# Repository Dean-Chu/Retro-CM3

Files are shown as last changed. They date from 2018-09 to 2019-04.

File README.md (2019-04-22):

# Retro-CM3

Yet another retropie console. 

Build with Raspberry Pi Compute Module 3 Lite. As powerful as Rpi3B, but as small as Rpi 0.

The final size of this console is within 155x61x15mm with 2 hours batter life.

Support most of the emulators provided by retropie.

Run PS1 N64 smoothly, able to run most 2D and some of 3D PSP games.

Assamble video: https://www.bilibili.com/video/av24430157

Flashable image： http://soft.nyko.moe/Game/RetroPie/CM3/retro-cm3v42-no-rom-v3.7z
Alternative link: https://drive.google.com/file/d/1JxBlyW3KhkUhTjVssIsfI8lL1l42jLt7/view?usp=sharing

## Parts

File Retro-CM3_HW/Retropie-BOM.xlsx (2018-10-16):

COMPONENT |  | footprint | value
SKRRAAE010 | A, B, DOWN, LEFT, RIGHT, UP, X, Y | SKRRAAE010
AN9250 | A1 | AN9520
XH2.54-2p | BT1 | XH2.54-2
CAP | C1, C4 | 0603-CAP | 2.2nF
CAP | C12, C28, C42, C43, C44, C51, C55, C58, C60 | 0805-CAP | 10uF
CAP | C19 | 0603-CAP | 0.33uF
CAP | C2, C45, C46, C48 | 1206-CAP | 47uF
CAP | C21, C32, C33, C37, C38, C39 | C3216 | 100uF/6v
CAP | C25, C31, C34, C36 | 0603-CAP | 0.1uF
CAP | C3, C7, C8, C9, C10, C13, C14, C17, C18, C24, C29, C30, C35, C49, C52, C53, C56, C59, C61, C62 | 0603-CAP | 100nF
CAP | C5, C15, C16, C20, C22, C26, C27,C40, C41 | 0805-CAP | 22uF
CAP | C50 | 0805-CAP | 3.3uF
CAP | C54, C57 | 0603-CAP | 2.2uF
PJS008-2000-0 | CN1 | PJS008-2000-0
LED-GREEN | D1 | 0603_LED
LED-RED | D2 | 0603_LED
LED-BLUE | D3 | 0603_LED
BAT54C | D4 | SOT-23_L
1N5819/SS14 | D6 | SMA
PJ-327 | J1 | pj-327 |  | 手补
Micro USB | J2 | USB micro
BUTTONS | L, R | 6*6*5mm |  | 手补
CD32 INDUCTOR | L1 | CD32 | 22uH
MHCI04020-1R2M | L2 | MHCI04020-1R2M | 1.2uH
MHCI04020-4R7M | L3, L4 | MHCI04020-4R7M | 4.7uH
SPEAKER | LS1 | 28*9*4 |  | 手补
SKRTLABE010 | PWR | SKRTLABE010
8050 | Q1, Q4, Q5, Q7 | SOT-23_L
Si2305 | Q2, Q3, Q6 | SOT23-3L
RES | R1,R20 | 0603-RES | 0
RES | R10, R11, R24, R39, R45 | 0603-RES | 100K
RES | R12, R16, R18, R22, R23, R34, R37, R41 | 0603-RES | 100K
RES | R14, R17 | 0603-RES | 4.7
RES | R2, R13, R15, R28, R30, R38, R44, R9 | 0603-RES | 1K
RES | R21 | 0603-RES | 200K
RES | R25 | 0603-RES | 0
RES | R26, R32 | 0603-RES | 20K
RES | R3, R4 | 0603-RES | 470
RES | R33 | 0603-RES | 820
RES | R35 | 0603-RES | 200K
RES | R36 | 0603-RES | 22K
RES | R5, R6, R7, R8, R19, R27, R29, R40 | 0603-RES | 10K
SKRAAME010 | SEL, STA | SKRAAME010
STM8S003F3 | U1 | TSOP65P640-20AN
PCM5100APWR | U10 | TSOP-20
AMP 2-1827236-4 | U11 | DDR2-SODIMM
RL-UM02BS | U2 | RL-UM02BS
TDA2822 | U3 | SOP-8
SY8008B | U4, U6 | SOT23-5AL
SP6205-3.3 | U5, U7 | SOT23-5AL
MP2617-GL | U8 | QFN-20
PT4103 | U9 | SOT26A-6N
FH35C-49S-0.3SHW | U12

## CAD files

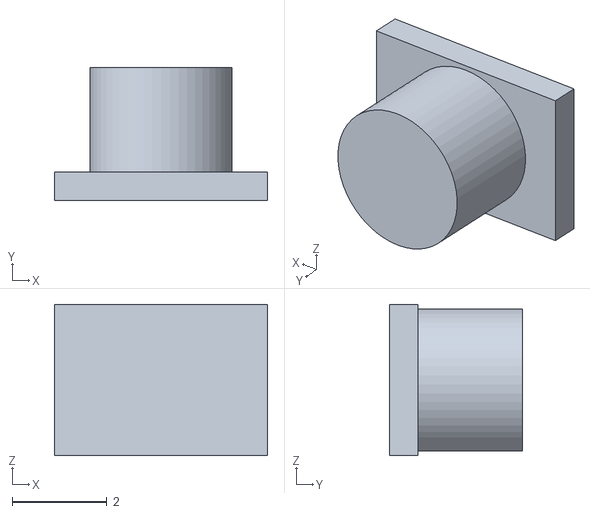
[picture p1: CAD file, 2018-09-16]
Retro-CM3_STL/PWR.STL
4.50 x 2.80 x 3.20

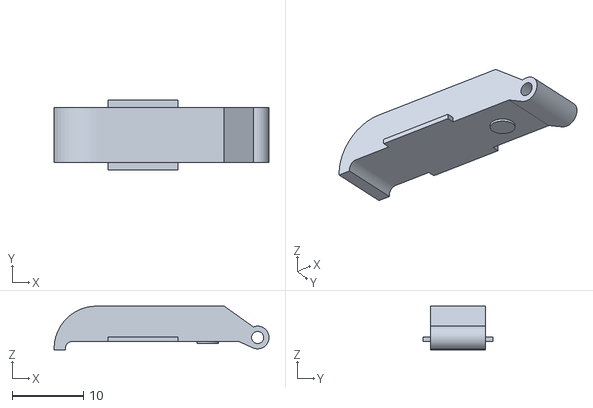
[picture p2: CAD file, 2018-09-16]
Retro-CM3_STL/LR.STL
30.2 x 9.80 x 6.17

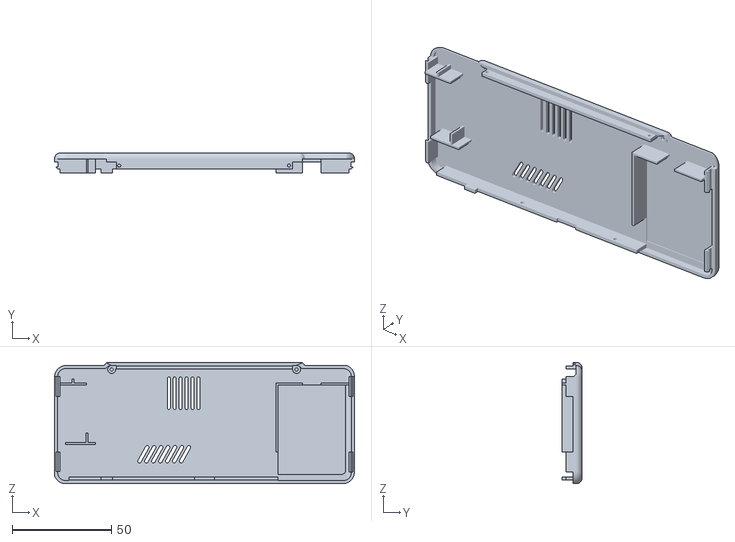
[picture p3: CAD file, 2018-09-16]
Retro-CM3_STL/BOTTOM-v4.STL
151.2 x 10.2 x 61.2

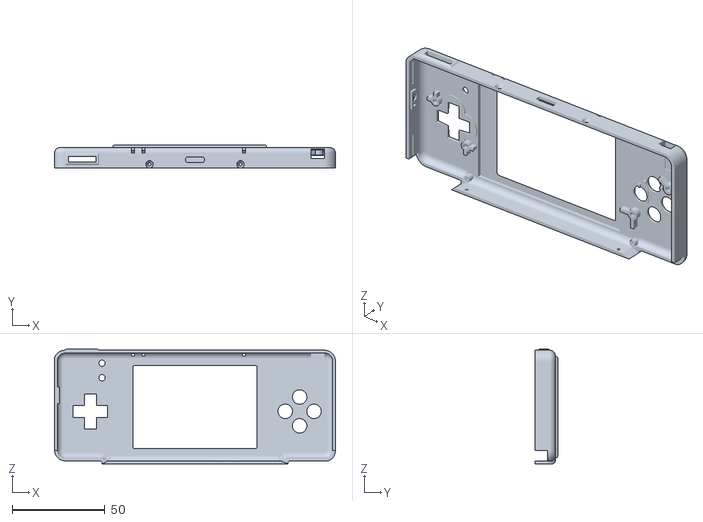
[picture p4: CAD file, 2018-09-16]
Retro-CM3_STL/TOP-v4.STL
151.2 x 12.4 x 61.8

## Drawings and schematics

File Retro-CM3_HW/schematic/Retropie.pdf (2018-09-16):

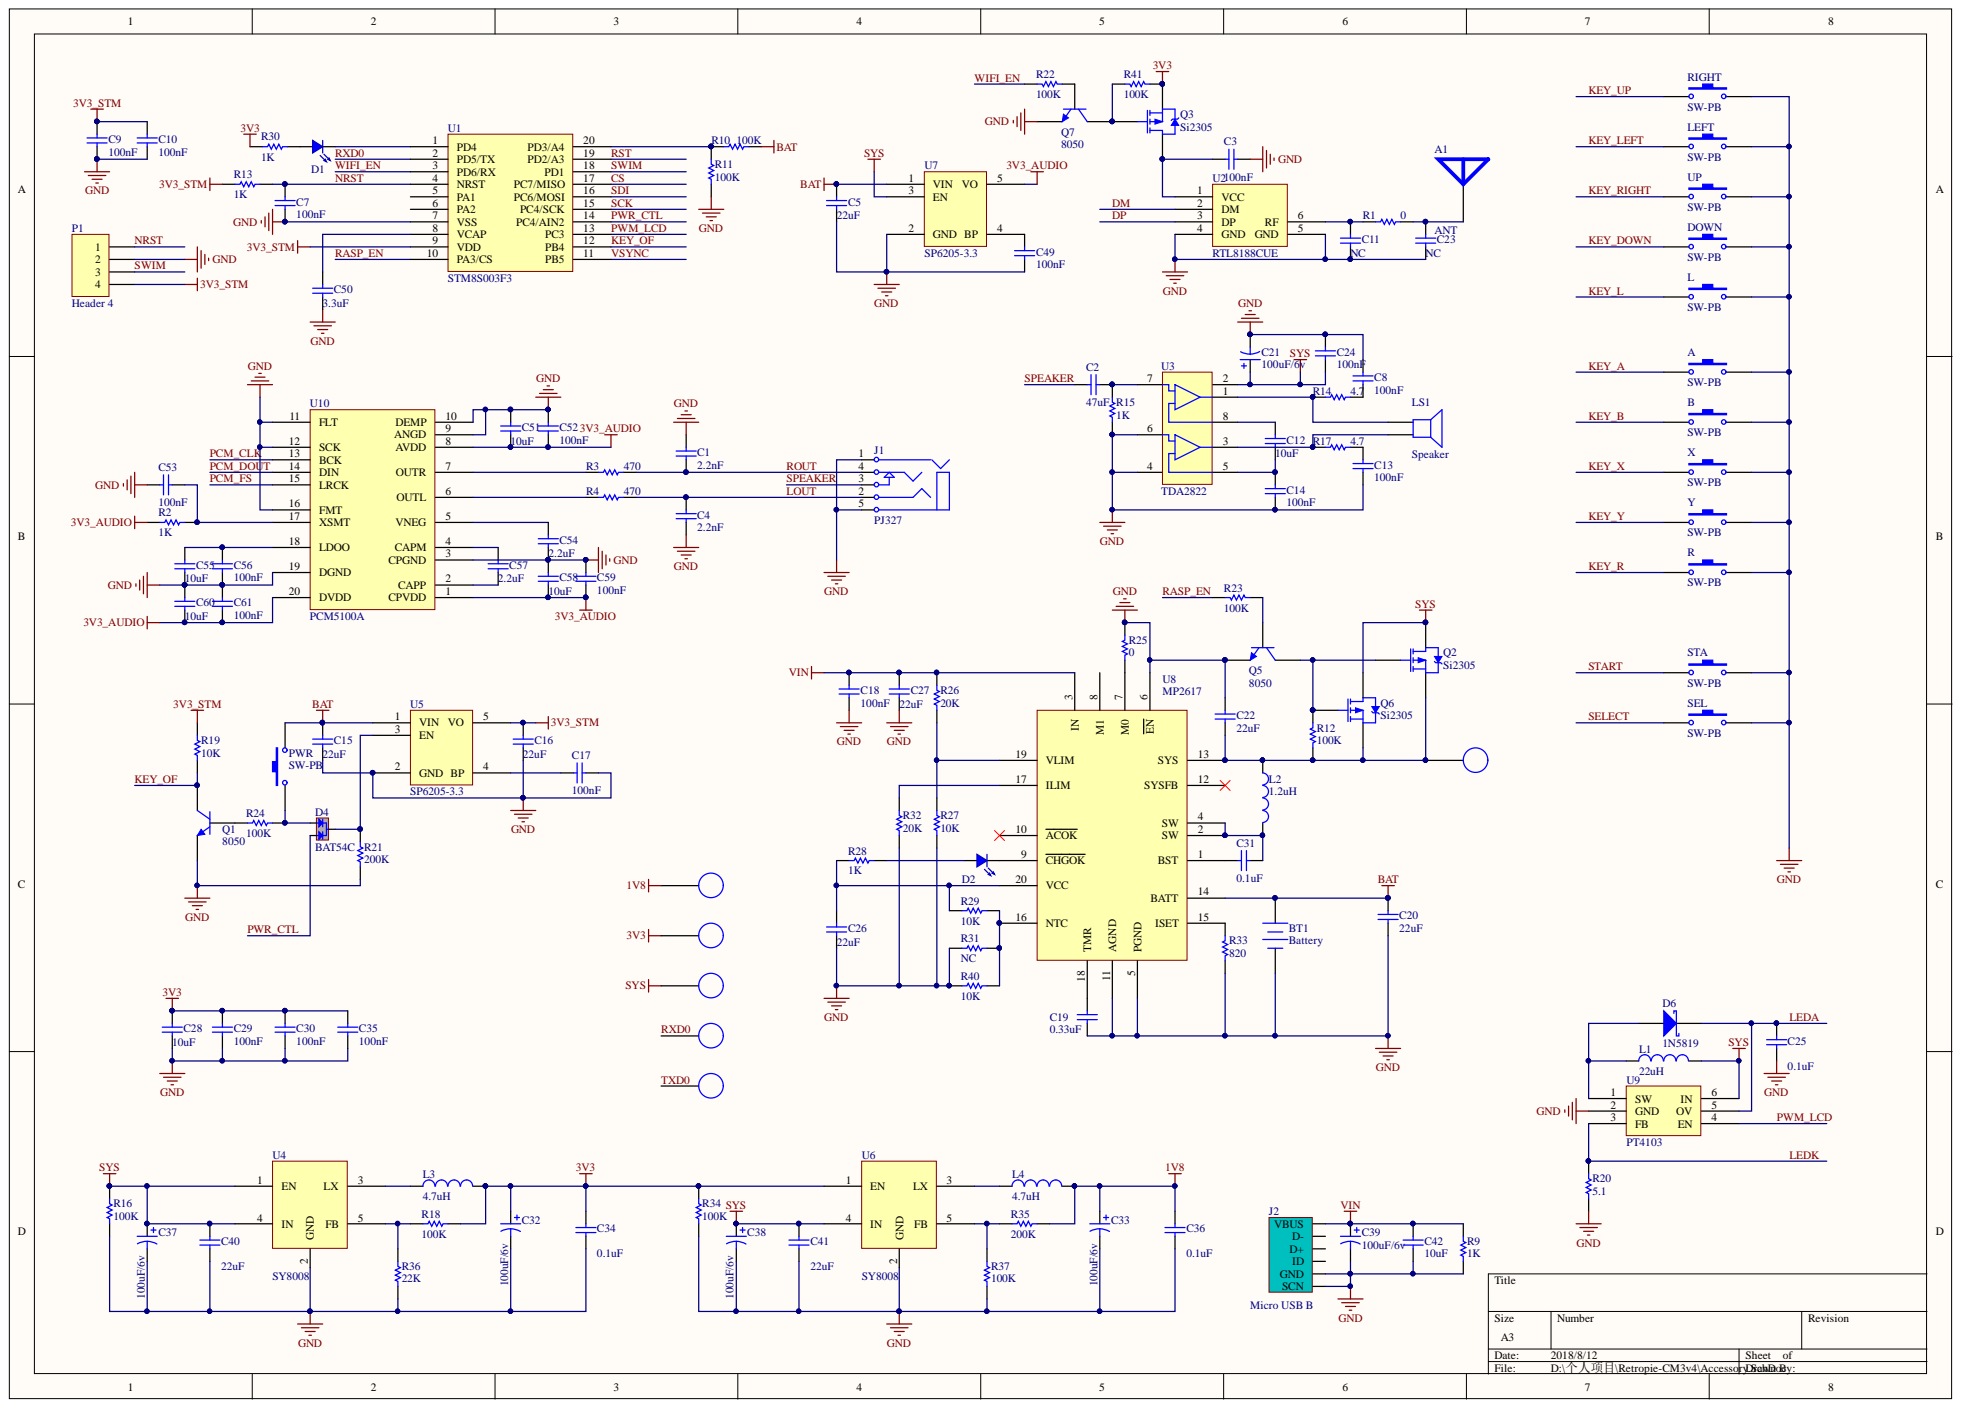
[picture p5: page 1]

BCK 13

LDOO 18

10uF | 100nF | | DVDD 20

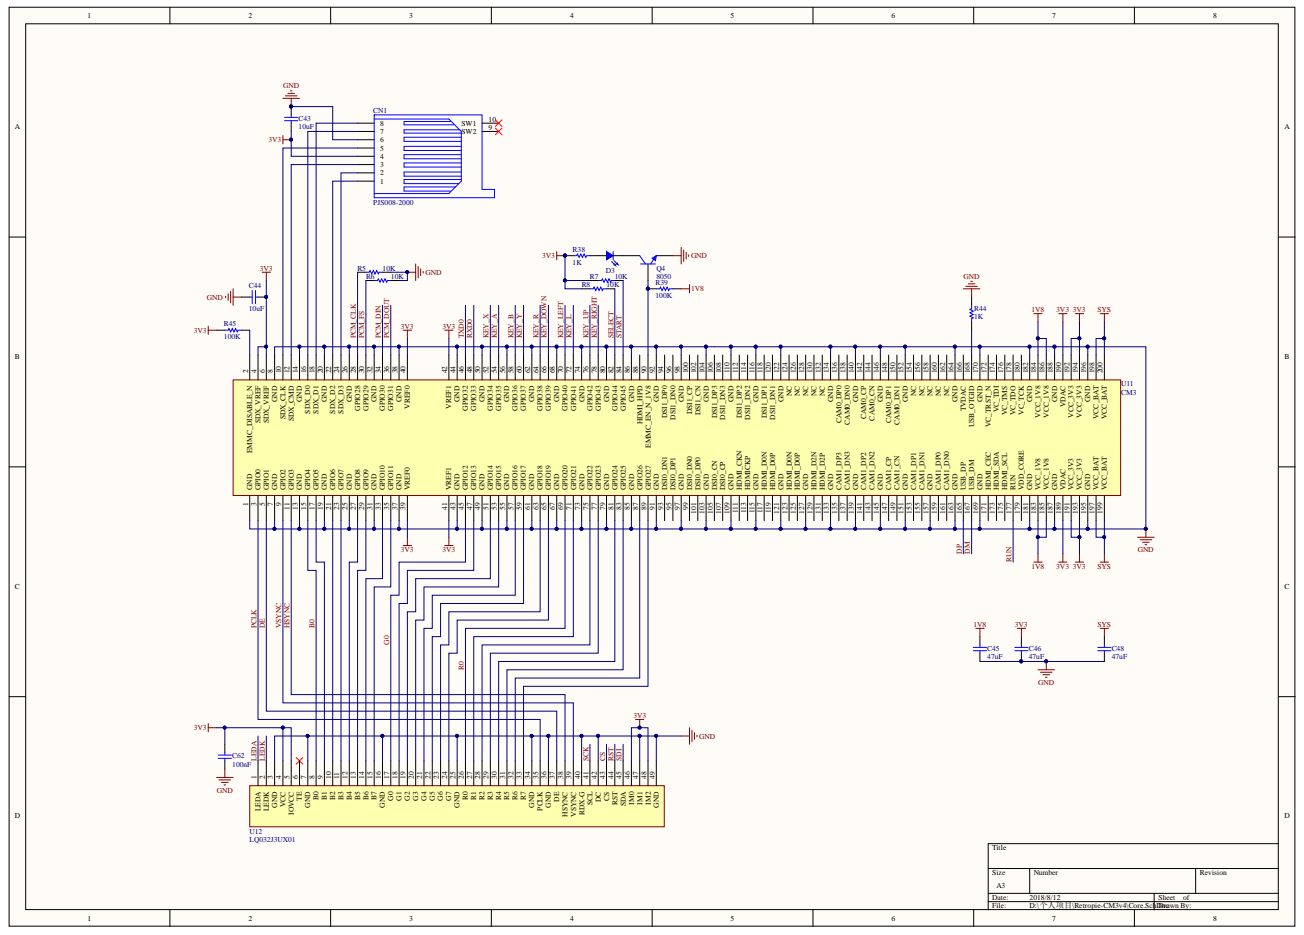
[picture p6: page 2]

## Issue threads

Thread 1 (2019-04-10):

Anywhere I can get the Retro-CM3?

wolfshow, 2019-04-10:
Dr. Zhu,

Is there anywhere I can get or buy the Retro-CM3?

Dean-Chu, 2019-04-22:
I only made 50 R-CM3 last year and all of them were sold out then. I'm working with some AliExpress global seller for a new version R-CM3 and it will be available before July if nothing goes wrong.
The new version will include an analog joystick, an injection-modeled case and a larger battery which ensures 6h playing time.
Also, if you can't wait that long, several CM3 game consoles (may be based on this repo?) can be found on Taobao.com, like "GAMEPI".
Anyway, I'll let you know as soon as the new version RCM3 is available.

wolfshow, 2019-04-22:
Thanks Dr. Zhu! Please let me know when it is ready.
btw: I am also located in Beijing. Would it be possible that I get the R-CM3 faster?

Dean-Chu, 2019-04-22:
The PCB and cases are still under testing and that will take some time.
If there are any final samples, I'll let you know.  :)

wolfshow, 2019-04-22:
Thank you so much! I am very very impressed by your Retro-CM3 and Retro-V3S products.

wolfshow, 2019-04-26:
Dr. Zhu, I would like to first use your open source pcb design to make one console for myself. Do you have any recommendation on where to buy the components and make pcb+smt?

Dean-Chu, 2019-04-27:
Be aware there are fake MP2617 in the market. Make sure you have tested the sample before buying more.

djkrieger, 2019-10-10:
Hi, is there a safe shutdown in de design? And can I use a normal switch instead of a pushdown one?

bademux, 2019-10-13:
Looks like we have something very similar on AliExpress https://www.aliexpress.com/item/33046920644.html
Is it RetroCM3?

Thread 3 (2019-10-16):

Cm3 schematic

djkrieger, 2019-10-16:
Hi,

In the schematic ar some cirkels connected to 1v8 and others. Are these some sort of test pads?  Also you are using a push button for the power button , can this be an sliding switch instead, like the original dmg?

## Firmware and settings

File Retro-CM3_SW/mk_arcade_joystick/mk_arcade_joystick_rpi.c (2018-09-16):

/*
 *  Arcade Joystick Driver for RaspberryPi
 *
 *  Copyright (c) 2014 Matthieu Proucelle
 *
 *  Based on the gamecon driver by Vojtech Pavlik, and Markus Hiienkari
 */


/*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
 * You should have received a copy of the GNU General Public License
 * along with this program; if not, write to the Free Software
 * Foundation, Inc., 51 Franklin Street, Fifth Floor, Boston,
 * MA 02110-1301, USA.
 */

#define pr_fmt(fmt) KBUILD_MODNAME ": " fmt

#include <linux/kernel.h>
#include <linux/delay.h>
#include <linux/module.h>
#include <linux/init.h>
#include <linux/input.h>
#include <linux/mutex.h>
#include <linux/slab.h>

#include <linux/ioport.h>
#include <asm/io.h>


MODULE_AUTHOR("Matthieu Proucelle");
MODULE_DESCRIPTION("GPIO and MCP23017 Arcade Joystick Driver");
MODULE_LICENSE("GPL");

#define MK_MAX_DEVICES		9

#ifdef RPI2
#define PERI_BASE        0x3F000000
#else
#define PERI_BASE        0x20000000
#endif

#define GPIO_BASE                (PERI_BASE + 0x200000) /* GPIO controller */

#define INP_GPIO(g) *(gpio+((g)/10)) &= ~(7<<(((g)%10)*3))
#define OUT_GPIO(g) *(gpio+((g)/10)) |=  (1<<(((g)%10)*3))
#define GPIO_READ(g)  *(gpio + ((g)/32) + 13) &= (1<<((g)%32))

#define SET_GPIO_ALT(g,a) *(gpio+(((g)/10))) |= (((a)<=3?(a)+4:(a)==4?3:2)<<(((g)%10)*3))

#define GPIO_SET *(gpio+7)
#define GPIO_CLR *(gpio+10)

#define BSC1_BASE		(PERI_BASE + 0x804000)


/*
 * MCP23017 Defines
 */
#define MPC23017_GPIOA_MODE		0x00
#define MPC23017_GPIOB_MODE		0x01
#define MPC23017_GPIOA_PULLUPS_MODE	0x0c
#define MPC23017_GPIOB_PULLUPS_MODE	0x0d
#define MPC23017_GPIOA_READ             0x12
#define MPC23017_GPIOB_READ             0x13

/*
 * Defines for I2C peripheral (aka BSC, or Broadcom Serial Controller)
 */

#define BSC1_C		*(bsc1 + 0x00)
#define BSC1_S		*(bsc1 + 0x01)
#define BSC1_DLEN	*(bsc1 + 0x02)
#define BSC1_A		*(bsc1 + 0x03)
#define BSC1_FIFO	*(bsc1 + 0x04)

#define BSC_C_I2CEN	(1 << 15)
#define BSC_C_INTR	(1 << 10)
#define BSC_C_INTT	(1 << 9)
#define BSC_C_INTD	(1 << 8)
#define BSC_C_ST	(1 << 7)
#define BSC_C_CLEAR	(1 << 4)
#define BSC_C_READ	1

#define START_READ	BSC_C_I2CEN|BSC_C_ST|BSC_C_CLEAR|BSC_C_READ
#define START_WRITE	BSC_C_I2CEN|BSC_C_ST

#define BSC_S_CLKT	(1 << 9)
#define BSC_S_ERR	(1 << 8)
#define BSC_S_RXF	(1 << 7)
#define BSC_S_TXE	(1 << 6)
#define BSC_S_RXD	(1 << 5)
#define BSC_S_TXD	(1 << 4)
#define BSC_S_RXR	(1 << 3)
#define BSC_S_TXW	(1 << 2)
#define BSC_S_DONE	(1 << 1)
#define BSC_S_TA	1

#define CLEAR_STATUS	BSC_S_CLKT|BSC_S_ERR|BSC_S_DONE

static volatile unsigned *gpio;
static volatile unsigned *bsc1;

struct mk_config {
    int args[MK_MAX_DEVICES];
    unsigned int nargs;
};

static struct mk_config mk_cfg __initdata;

module_param_array_named(map, mk_cfg.args, int, &(mk_cfg.nargs), 0);
MODULE_PARM_DESC(map, "Enable or disable GPIO, MCP23017, TFT and Custom Arcade Joystick");

struct gpio_config {
    int mk_arcade_gpio_maps_custom[12];
    unsigned int nargs;
};

static struct gpio_config gpio_cfg __initdata;

module_param_array_named(gpio, gpio_cfg.mk_arcade_gpio_maps_custom, int, &(gpio_cfg.nargs), 0);
MODULE_PARM_DESC(gpio, "Numbers of custom GPIO for Arcade Joystick");

enum mk_type {
    MK_NONE = 0,
    MK_ARCADE_GPIO,
    MK_ARCADE_GPIO_BPLUS,
    MK_ARCADE_MCP23017,
    MK_ARCADE_GPIO_TFT,
    MK_ARCADE_GPIO_CUSTOM,
    MK_MAX
};

#define MK_REFRESH_TIME	HZ/100

struct mk_pad {
    struct input_dev *dev;
    enum mk_type type;
    char phys[32];
    int mcp23017addr;
    int gpio_maps[12]
};

struct mk_nin_gpio {
    unsigned pad_id;
    unsigned cmd_setinputs;
    unsigned cmd_setoutputs;
    unsigned valid_bits;
    unsigned request;
    unsigned request_len;
    unsigned response_len;
    unsigned response_bufsize;
};

struct mk {
    struct mk_pad pads[MK_MAX_DEVICES];
    struct timer_list timer;
    int pad_count[MK_MAX];
    int used;
    struct mutex mutex;
};

struct mk_subdev {
    unsigned int idx;
};

static struct mk *mk_base;

static const int mk_max_arcade_buttons = 12;

// Map of the gpios :                     up, down, left, right, start, select, a,  b,  tr, y,  x,  tl
//static const int mk_arcade_gpio_maps[] = {4,  17,    27,  22,    10,    9,      25, 24, 23, 18, 15, 14 };
static const int mk_arcade_gpio_maps[] = {42,39,40,43,45,44,35,36,38,37,34,41};
// 2nd joystick on the b+ GPIOS                 up, down, left, right, start, select, a,  b,  tr, y,  x,  tl
static const int mk_arcade_gpio_maps_bplus[] = {11, 5,    6,    13,    19,    26,     21, 20, 16, 12, 7,  8 };
// Map of the mcp23017 on GPIOA            up, down, left, right, start, select
static const int mk_arcade_gpioa_maps[] = {0,  1,    2,    3,     4,     5      };

// Map of the mcp23017 on GPIOB            a, b, tr, y, x, tl
static const int mk_arcade_gpiob_maps[] = {0, 1, 2,  3, 4, 5 };

// Map joystick on the b+ GPIOS with TFT      up, down, left, right, start, select, a,  b,  tr, y,  x,  tl
static const int mk_arcade_gpio_maps_tft[] = {21, 13,    26,    19,    5,    6,     22, 4, 20, 17, 27,  16 };

static const short mk_arcade_gpio_btn[] = {
    BTN_START, BTN_SELECT, BTN_A, BTN_B, BTN_TR, BTN_Y, BTN_X, BTN_TL
};

static const char *mk_names[] = {
    NULL, "GPIO Controller 1", "GPIO Controller 2", "MCP23017 Controller", "GPIO Controller 1" , "GPIO Controller 1"
};

/* GPIO UTILS */
static void setGpioPullUps_1(int pullUps) {
    *(gpio + 37) = 0x02;
    udelay(10);
    *(gpio + 38) = pullUps;
    udelay(10);
    *(gpio + 37) = 0x00;
    *(gpio + 38) = 0x00;
}

static void setGpioPullUps_2(int pullUps) {
    *(gpio + 37) = 0x02;
    udelay(10);
    *(gpio + 39) = pullUps;
    udelay(10);
    *(gpio + 37) = 0x00;
    *(gpio + 39) = 0x00;
}


static void setGpioAsInput(int gpioNum) {
    INP_GPIO(gpioNum);
}

static int getPullUpMask_1(int gpioMap[]){
    int mask = 0x0000000;
    int i;
    for(i=0; i<12;i++) {
        if(gpioMap[i] != -1 && gpioMap[i] < 32){   // to avoid unused pins
            int pin_mask  = 1<<gpioMap[i];
            mask = mask | pin_mask;
        }
    }
    return mask;
}

static int getPullUpMask_2(int gpioMap[]){
    int mask = 0x0000000;
    int i;
    for(i=0; i<12;i++) {
        if(gpioMap[i] != -1 && gpioMap[i] > 31){   // to avoid unused pins
            int pin_mask  = 1<<(gpioMap[i]-32);
            mask = mask | pin_mask;
        }
    }
    return mask;
}

/* I2C UTILS */
static void i2c_init(void) {
    INP_GPIO(2);
    SET_GPIO_ALT(2, 0);
    INP_GPIO(3);
    SET_GPIO_ALT(3, 0);
}

static void wait_i2c_done(void) {
    while ((!((BSC1_S) & BSC_S_DONE))) {
        udelay(100);
    }
}

// Function to write data to an I2C device via the FIFO.  This doesn't refill the FIFO, so writes are limited to 16 bytes
// including the register address. len specifies the number of bytes in the buffer.
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

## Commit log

2018-09-16 init commit
    [2.GBL, 2.GBO, 2.GBP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]
2018-10-16 added bom list
    [Retropie-BOM.xlsx]

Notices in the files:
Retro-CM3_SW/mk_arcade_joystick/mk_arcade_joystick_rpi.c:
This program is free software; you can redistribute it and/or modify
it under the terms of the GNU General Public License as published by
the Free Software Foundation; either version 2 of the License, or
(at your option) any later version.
